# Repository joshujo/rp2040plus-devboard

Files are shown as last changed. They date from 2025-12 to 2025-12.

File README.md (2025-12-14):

# RP2040+ Devboard

This is a devboard that is designed to have a basic sensor, OLED screen, buttons and LEDs pre-embedded onto the board. The idea of this design was to have some basic hardware already available on the develepment board itself so an external bread board and some additional components with a kit and such is not needed to use it. Additionally, it can be used as a simple console or just a temperature monitor if desired. The board is designed to be extended with an additional 17 GPIO pins exposed to the user for prototyping. 

## Features

- 17 GPIO pins exposed
- HDC1080 accurate temperature + humidity sensor
- Buzzer
- OLED screen
- USB-C connector for power + data
- An additional power only USB-C connector designed to have an external battery plugged in
- 10 NeoPixel LEDs
- Programmable matrix buttons
- Up to 900mA +3V3
- Up to 3A VBUS
- 13 programmable buttons
- Designed to be used as is, no external bread board or components needed
- Moderate form factor of 100x40mm
- RP2040 comes with another I<sup>2</sup>C bus for more external components

# Datasheet

## Base
HDC1080 Addr: 1000000\
OLED Addr: 0111100 or 0111101\
Buzzer: GPIO24\
LED: GPIO25\
Neopixels: GPIO14

## Keypad
Shift: GPIO13\
ROW0: GPIO15\
ROW1: GPIO16\
ROW2: GPIO17\
ROW3: GPIO18\
COL0: GPIO19\
COL1: GPIO20\
COL2: GPIO21

## I<sud>2</sud>C
SDA: GPIO22\
SCL: GPIO23

# Schematic


# PCB


RP2040 Devboard

# BOM

| Item | Description | Quantity(For 5 units at minimum order amount) | Unit Price | Total Price | URL | Running Total |
| --- | --- | --- | --- | --- | --- | --- |
| CL05A105KP5NNNC | 10V 1uF X5R ±10% 0402 Ceramic Capacitors RoHS | 100 | 0.0017 | $0.17 | [https://www.lcsc.com/product-detail/C14445.html](https://www.lcsc.com/product-detail/C14445.html) | $0.17 |
| CL05B104KO5NNNC | 16V 100nF X7R ±10% 0402 Ceramic Capacitors RoHS | 100 | 0.0012 | $0.12 | [https://www.lcsc.com/product-detail/C1525.html](https://www.lcsc.com/product-detail/C1525.html) | $0.29 |
| CC0603JRNPO9BN330 | 50V 33pF NP0 ±5% 0603 Ceramic Capacitors RoHS | 100 | 0.0024 | $0.24 | [https://www.lcsc.com/product-detail/C107047.html](https://www.lcsc.com/product-detail/C107047.html) | $0.53 |
| CL10B104KB8NNNC | 50V 100nF X7R ±10% 0603 Ceramic Capacitors RoHS | 100 | 0.0026 | $0.26 | [https://www.lcsc.com/product-detail/C1591.html](https://www.lcsc.com/product-detail/C1591.html) | $0.79 |
| CL10A106KP8NNNC | 10V 10uF X5R ±10% 0603 Ceramic Capacitors RoHS | 50 | 0.0058 | $0.29 | [https://www.lcsc.com/product-detail/C19702.html](https://www.lcsc.com/product-detail/C19702.html) | $1.08 |
| CL10A105KB8NNNC | 50V 1uF X5R ±10% 0603 Ceramic Capacitors RoHS | 50 | 0.0049 | $0.25 | [https://www.lcsc.com/product-detail/C15849.html](https://www.lcsc.com/product-detail/C15849.html) | $1.33 |
| CL31A107MQHNNNE | 6.3V 100uF X5R ±20% 1206 Ceramic Capacitors RoHS | 20 | 0.0552 | $1.10 | [https://www.lcsc.com/product-detail/C15008.html](https://www.lcsc.com/product-detail/C15008.html) | $2.43 |
| KT-0805B | 5mA 100mcd 460nm~475nm Blue 100mW 3.1V 0805 LED Indication - Discrete RoHS | 50 | 0.0117 | $0.59 | [https://www.lcsc.com/product-detail/C2293.html](https://www.lcsc.com/product-detail/C2293.html) | $3.02 |
| CD4148WSP | 1A 4ns Independent 75V 1.25V@100mA 150mA 0805 Single Diodes RoHS | 100 | 0.0118 | $1.18 | [https://www.lcsc.com/product-detail/C30584799.html](https://www.lcsc.com/product-detail/C30584799.html) | $4.20 |
| WS2812B-2020 | SMD,2.2x2mm LED Addressable, Specialty RoHS | 60 | 0.0658 | $3.95 | [https://www.lcsc.com/product-detail/C965555.html](https://www.lcsc.com/product-detail/C965555.html) | $8.15 |
| TYPE-C-31-M-12 | 1 16P Type-C SMD USB, DVI, HDMI Connector Assemblies RoHS | 5 | 0.1762 | $0.88 | [https://www.lcsc.com/product-detail/C165948.html](https://www.lcsc.com/product-detail/C165948.html) | $9.03 |
| SKTDLHE010 | Without Bracket Rectangular Button No 3.9mm SPST SMD Tactile Switches RoHS | 10 | 0.1646 | $1.65 | [https://www.lcsc.com/product-detail/C380198.html](https://www.lcsc.com/product-detail/C380198.html) | $10.68 |
| SKSLLBE010 | 12V 2.2mm Round Button No 4.5mm SPST 50mA SMD,4.5x2.2mm Tactile Switches RoHS | 65 | 0.159 | $10.34 | [https://www.lcsc.com/product-detail/C358617.html](https://www.lcsc.com/product-detail/C358617.html) | $21.02 |
| RP2040 | 133MHz 30 LQFN-56(7x7) Microcontrollers RoHS | 3 | 0.9482 | $2.84 | [https://www.lcsc.com/product-detail/C2040.html](https://www.lcsc.com/product-detail/C2040.html) | $23.86 |
| HDC1080DMBR | ±2%RH -40℃~+125℃ 0%RH~100%RH I2C WSON-6(3x3) Humidity, Moisture Sensors RoHS | 5 | 0.9001 | $4.50 | [https://www.lcsc.com/product-detail/C82227.html](https://www.lcsc.com/product-detail/C82227.html) | $28.36 |
| NX3225GA-12MHZ-STD-CRG-2 | 8pF SMD3225-4P Crystals RoHS | 5 | 0.257 | $1.29 | [https://www.lcsc.com/product-detail/C481407.html](https://www.lcsc.com/product-detail/C481407.html) | $29.65 |
| MLT-8530 | 80dB Passive (Externally Driven) 2.7kHz 3.6V Electromagnetic SMD,8.5x8.5mm Alarms, Buzzers, and Sirens RoHS | 5 | 0.1941 | $0.97 | [https://www.lcsc.com/product-detail/C94599.html](https://www.lcsc.com/product-detail/C94599.html) | $30.62 |
| TPS2116DRLR | 2 Active High 2.5A SOT-583 Power Distribution Switches, Load Drivers RoHS | 5 | 0.3756 | $1.88 | [https://www.lcsc.com/product-detail/C3235557.html](https://www.lcsc.com/product-detail/C3235557.html) | $32.50 |
| HS96L03W2C03 | 0.96 128x64 SSD1315 I2C LCD, OLED, Graphic RoHS | 5 | 2.0084 | $10.04 | [https://www.lcsc.com/product-detail/C5248080.html](https://www.lcsc.com/product-detail/C5248080.html) | $42.54 |
| W25Q128JVSIQ | 128Mbit 2.7V~3.6V 133MHz SPI SOIC-8-208mil Memory (ICs) RoHS | 5 | 1.5657 | $7.83 | [https://www.lcsc.com/product-detail/C97521.html](https://www.lcsc.com/product-detail/C97521.html) | $50.37 |
| NCP1117ST33T3G | 62dB@(120Hz) Positive Fixed 3.3V SOT-223 Voltage Regulators - Linear, Low Drop Out (LDO) Regulators RoHS | 5 | 0.2315 | $1.16 | [https://www.lcsc.com/product-detail/C26537.html](https://www.lcsc.com/product-detail/C26537.html) | $51.53 |
| BSS138LT1G | 50V 200mA 225mW 5.6Ω@2.75V One N-channel SOT-23 Single FETs, MOSFETs RoHS | 20 | 0.0342 | $0.68 | [https://www.lcsc.com/product-detail/C82045.html](https://www.lcsc.com/product-detail/C82045.html) | $52.21 |
| FRC0603F27R4TS | 100mW 27.4Ω 75V ±100ppm/℃ Thick Film Resistor ±1% 0603 Chip Resistor - Surface Mount RoHS | 100 | 0.0009 | $0.09 | [https://www.lcsc.com/product-detail/C5126244.html](https://www.lcsc.com/product-detail/C5126244.html) | $52.30 |
| 0603WAF4700T5E | 100mW 470Ω 75V ±100ppm/℃ Thick Film Resistor ±1% 0603 Chip Resistor - Surface Mount RoHS | 100 | 0.0012 | $0.12 | [https://www.lcsc.com/product-detail/C23179.html](https://www.lcsc.com/product-detail/C23179.html) | $52.42 |
| AR03BTCX5001 | 100mW 5kΩ 75V ±25ppm/℃ Thin Film Resistor ±0.1% 0603 Chip Resistor - Surface Mount RoHS | 20 | 0.0302 | $0.60 | [https://www.lcsc.com/product-detail/C2828621.html](https://www.lcsc.com/product-detail/C2828621.html) | $53.02 |
| RC0603FR-07100RL | 100mW 100Ω 75V ±100ppm/℃ Thick Film Resistor ±1% 0603 Chip Resistor - Surface Mount RoHS | 100 | 0.0011 | $0.11 | [https://www.lcsc.com/product-detail/C105588.html](https://www.lcsc.com/product-detail/C105588.html) | $53.13 |
| FRC0603F5101TS | 100mW 5.1kΩ 75V ±100ppm/℃ Thick Film Resistor ±1% 0603 Chip Resistor - Surface Mount RoHS | 100 | 0.0009 | $0.09 | [https://www.lcsc.com/product-detail/C2907044.html](https://www.lcsc.com/product-detail/C2907044.html) | $53.22 |
| RC0603FR-0710KL | 100mW 10kΩ 75V ±100ppm/℃ Thick Film Resistor ±1% 0603 Chip Resistor - Surface Mount RoHS | 100 | 0.0011 | $0.11 | [https://www.lcsc.com/product-detail/C98220.html](https://www.lcsc.com/product-detail/C98220.html) | $53.33 |
| FRC0603F3302TS | 33kΩ 100mW 75V ±100ppm/℃ Thick Film Resistor ±1% 0603 Chip Resistor - Surface Mount RoHS | 100 | 0.0009 | $0.09 | [https://www.lcsc.com/product-detail/C2907028.html](https://www.lcsc.com/product-detail/C2907028.html) | $53.42 |
| PZ254V-11-03P | 3P 1x3P -40℃~+105℃ Pin Header Black 2.54mm 2.5mm 6mm 250V 3mm 1 3A Through Hole Through Hole,P=2.54mm Headers, Male Pins RoHS | 50 | 0.0162 | $0.81 | [https://www.lcsc.com/product-detail/C2937625.html](https://www.lcsc.com/product-detail/C2937625.html) | $54.23 |
| PZ254V-11-04P | 4P 1x4P -40℃~+105℃ Black Pin Header 2.54mm 2.5mm 6mm 250V 3mm 1 3A Through Hole Through Hole,P=2.54mm Headers, Male Pins RoHS | 20 | 0.0217 | $0.43 | [https://www.lcsc.com/product-detail/C2691448.html](https://www.lcsc.com/product-detail/C2691448.html) | $54.66 |
| 0402WGF1001TCE | 1kΩ 62.5mW 50V ±100ppm/℃ Thick Film Resistor ±1% 0402 Chip Resistor - Surface Mount RoHS | 100 | 0.0006 | $0.06 | [https://www.lcsc.com/product-detail/C11702.html](https://www.lcsc.com/product-detail/C11702.html) | $54.72 |
| KT-0805G | 5mA 430mcd 513nm\~528nm Emerald Green 100mW 2.6V\~3.1V 0805 LED Indication - Discrete RoHS | 50 | 0.0112 | $0.56 | [https://www.lcsc.com/product-detail/C2297.html](https://www.lcsc.com/product-detail/C2297.html) | $55.28 |
| TYPE-C 6P(073) | 1 6P -25℃~+85℃ Type-C SMD USB, DVI, HDMI Connector Assemblies RoHS | 10 | 0.0357 | $0.36 | [https://www.lcsc.com/product-detail/C668623.html](https://www.lcsc.com/product-detail/C668623.html) | $55.64 |

Plus $31.36 for the PCBs

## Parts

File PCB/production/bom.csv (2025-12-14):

Designator | Footprint | Quantity | Value | LCSC Part #
C1, C10 | 0402 | 2 | 1u
C11, C12, C2, C3, C4, C5, C6, C7, C8, C9 | 0402 | 10 | 100n
C13, C14 | 0603 | 2 | 10u
C15, C18, C19 | 0603 | 3 | 100n
C16, C17 | 0603 | 2 | 33p
C20 | 0603 | 1 | 1u
C21, C22, C23, C24, C25 | 1206 | 5 | 100u
D1, D2 | 0805 | 2 | KT-0805G
D10, D11, D12, D13, D14, D15, D3, D4, D5, D6, D7, D8, D9 | 0805 | 13 | CD4148W
D16, D17, D18, D19, D20, D21, D22, D23, D24, D25 | LED_WS2812B-2020_PLCC4_2.0x2.0mm | 10 | WS2812B-2020
J1 | USB_C_Receptacle_G-Switch_GT-USB-7010ASV | 1 | USB_C_Receptacle_USB2.0_14P
J2 | USB_C_Receptacle_GCT_USB4125-xx-x_6P_TopMnt_Horizontal | 1 | USB_C_Receptacle_PowerOnly_6P
J3, J4 | PinHeader_1x10_P2.54mm_Vertical | 2 | Conn_01x10_Pin
J5 | PinHeader_1x03_P2.54mm_Vertical | 1 | Conn_01x03_Pin
Q1 | SOT-23 | 1 | BSS138
R1, R2 | 0603 | 2 | 27.4
R10 | 0603 | 1 | 1k
R11 | 0402 | 1 | 1k
R12, R18, R19 | 0603 | 3 | 470
R13, R14, R15, R16 | 0603 | 4 | 5k
R17 | 0603 | 1 | 100
R3, R4, R5, R6 | 0603 | 4 | 5.1K
R7, R9 | 0603 | 2 | 10k
R8 | 0603 | 1 | 33k
SW1, SW10, SW11, SW12, SW13, SW14, SW15, SW2, SW3, SW4, SW5, SW6, SW7, SW8, SW9 | SW_Push_SPST_NO_Alps_SKRK | 15 | SW_Push
U1 | QFN-56-1EP_7x7mm_P0.4mm_EP3.2x3.2mm | 1 | RP2040
U2 | SOT-223-3_TabPin2 | 1 | NCP1117-3.3_SOT223
U3 | SOIC-8_5.3x5.3mm_P1.27mm | 1 | W25Q128JVS
U4 | HS96L03W2C03 | 1 | HS96L03W2C03
U5 | SOT-583-8 | 1 | TPS2116DRL
U7 | MLT-8530 | 1 | MLT-8530
U8 | Texas_S-PWSON-N6-HDC2080 | 1 | HDC1080
Y1 | Crystal_SMD_3225-4Pin_3.2x2.5mm_HandSoldering | 1 | NDK NX3225GA-12MHZ-STD-CRG-2

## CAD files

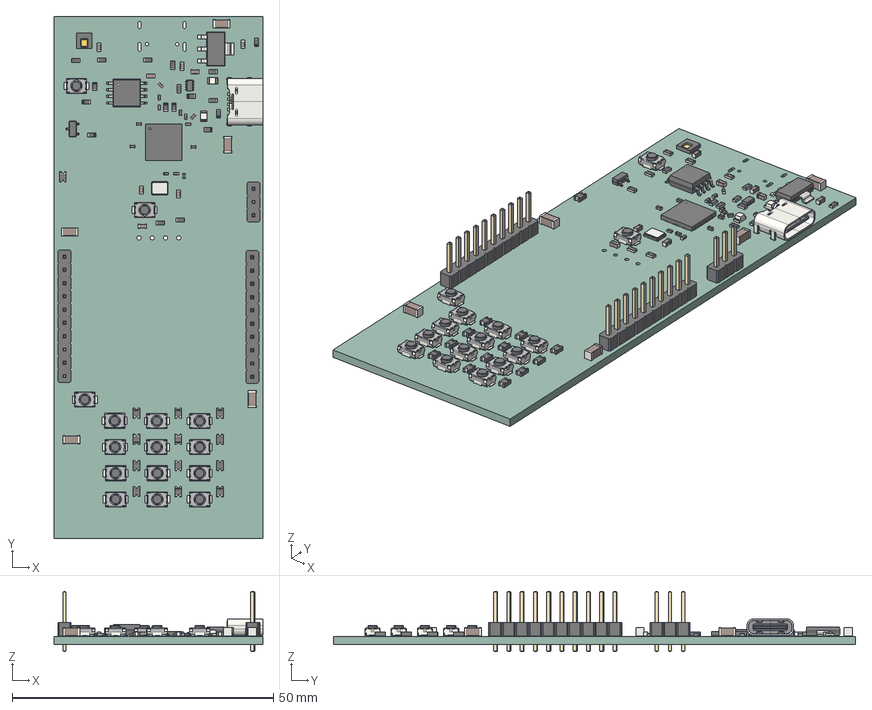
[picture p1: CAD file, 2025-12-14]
PCB/RP2040 Devboard.step
40.0 x 100.0 x 11.5 mm
D_0805_2012Metric x 13
R_0402_1005Metric
R_0603_1608Metric x 18
SW_Push_SPST_NO_Alps_SKRK x 15
C_1206_3216Metric x 5
Crystal_SMD_3225-4Pin_3.2x2.5mm
C_0402_1005Metric x 12
SOT-583-8
C_0603_1608Metric x 8
PinHeader_1x10_P2.54mm_Vertical x 2
PinHeader_1x03_P2.54mm_Vertical
LED_0805_2012Metric x 2
SOT-23
SOIC-8_5.3x5.3mm_P1.27mm
QFN-56-1EP_7x7mm_P0.4mm_EP3.2x3.2mm
SOT-223
USB_C_Receptacle_GCT_USB4125-xx-x_6P_TopMnt_Horizontal
Texas_S-PWSON-N6-HDC2080
RP2040 Devboard_PCB

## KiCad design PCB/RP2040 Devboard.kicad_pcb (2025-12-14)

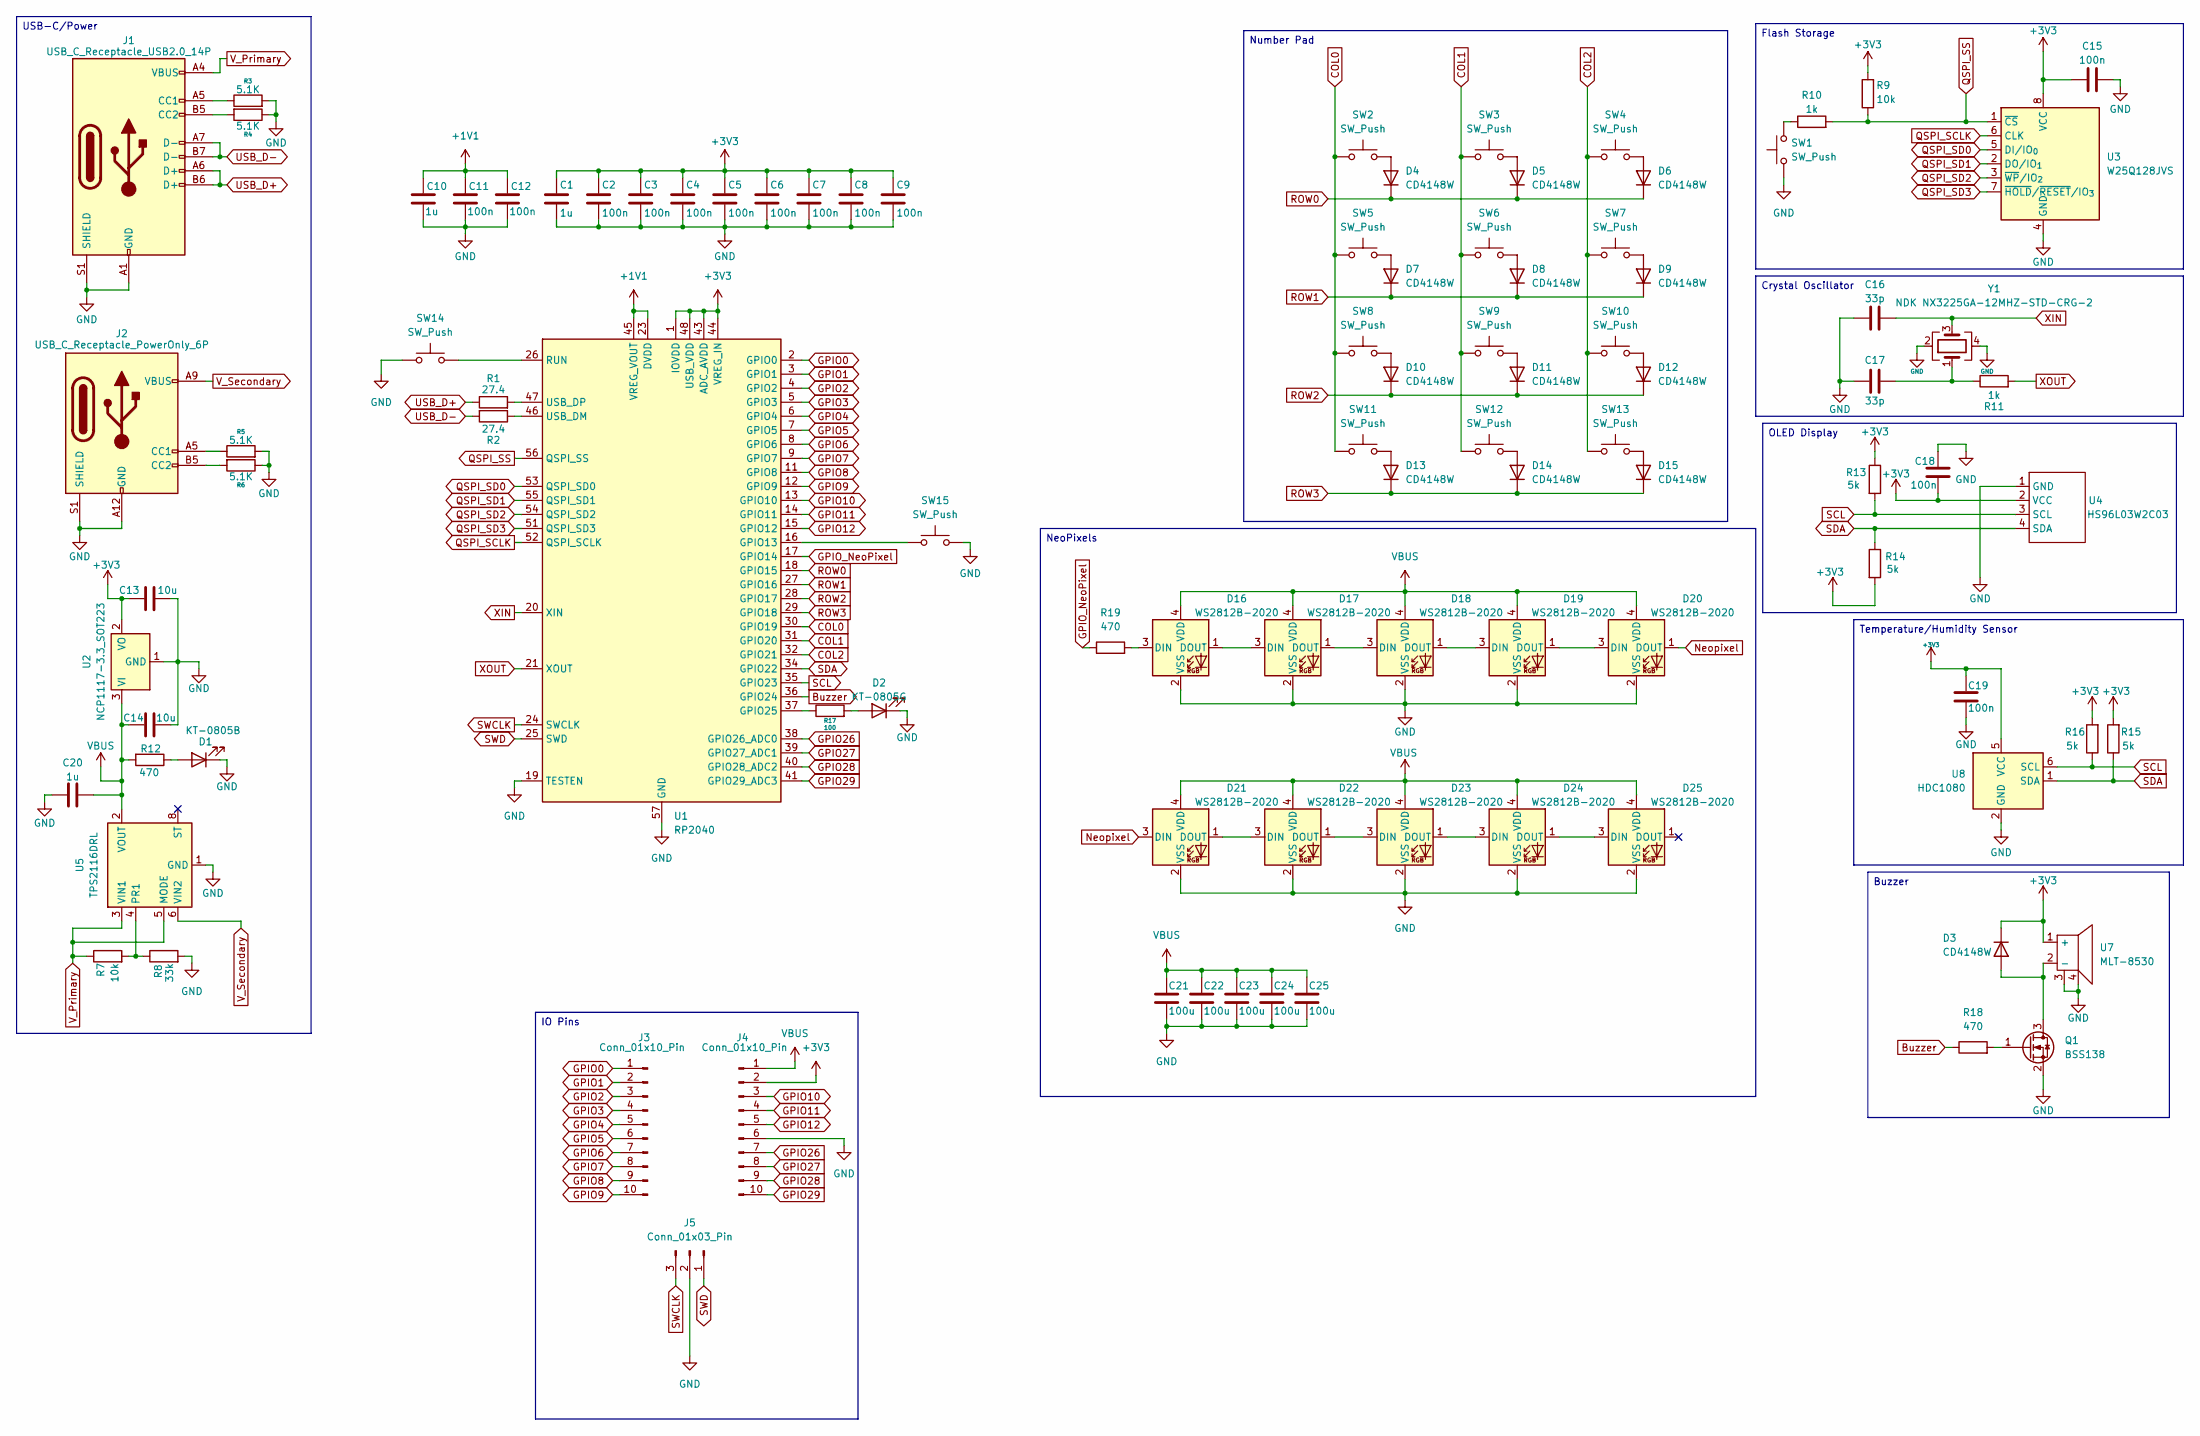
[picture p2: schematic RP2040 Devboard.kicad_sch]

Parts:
C1, C10: 1u; C_0402_1005Metric
C2, C3, C4, C5, C6, C7, C8, C9, C11, C12: 100n; C_0402_1005Metric
C13, C14: 10u; C_0603_1608Metric_Pad1.08x0.95mm_HandSolder
C15, C18, C19: 100n; C_0603_1608Metric_Pad1.08x0.95mm_HandSolder
C16, C17: 33p; C_0603_1608Metric_Pad1.08x0.95mm_HandSolder
C20: 1u; C_0603_1608Metric_Pad1.08x0.95mm_HandSolder
C21, C22, C23, C24, C25: 100u; C_1206_3216Metric_Pad1.33x1.80mm_HandSolder
D1: KT-0805B; LED_0805_2012Metric_Pad1.15x1.40mm_HandSolder
D2: KT-0805G; LED_0805_2012Metric_Pad1.15x1.40mm_HandSolder
D3, D4, D5, D6, D7, D8, D9, D10, D11, D12, D13, D14, D15: CD4148W; D_0805_2012Metric_Pad1.15x1.40mm_HandSolder
D16, D17, D18, D19, D20, D21, D22, D23, D24, D25: WS2812B-2020; LED_WS2812B-2020_PLCC4_2.0x2.0mm
J1: USB_C_Receptacle_USB2.0_14P; USB_C_Receptacle_G-Switch_GT-USB-7010ASV
J2: USB_C_Receptacle_PowerOnly_6P; USB_C_Receptacle_GCT_USB4125-xx-x_6P_TopMnt_Horizontal
J3, J4: Conn_01x10_Pin; PinHeader_1x10_P2.54mm_Vertical
J5: Conn_01x03_Pin; PinHeader_1x03_P2.54mm_Vertical
Q1: BSS138; SOT-23
R1, R2: 27.4; R_0603_1608Metric_Pad0.98x0.95mm_HandSolder
R3, R4, R5, R6: 5.1K; R_0603_1608Metric_Pad0.98x0.95mm_HandSolder
R7, R9: 10k; R_0603_1608Metric_Pad0.98x0.95mm_HandSolder
R8: 33k; R_0603_1608Metric_Pad0.98x0.95mm_HandSolder
R10: 1k; R_0603_1608Metric_Pad0.98x0.95mm_HandSolder
R11: 1k; R_0402_1005Metric
R12, R18, R19: 470; R_0603_1608Metric_Pad0.98x0.95mm_HandSolder
R13, R14, R15, R16: 5k; R_0603_1608Metric_Pad0.98x0.95mm_HandSolder
R17: 100; R_0603_1608Metric_Pad0.98x0.95mm_HandSolder
SW1, SW2, SW3, SW4, SW5, SW6, SW7, SW8, SW9, SW10, SW11, SW12, SW13, SW14, SW15: SW_Push; SW_Push_SPST_NO_Alps_SKRK
U1: RP2040; QFN-56-1EP_7x7mm_P0.4mm_EP3.2x3.2mm
U2: NCP1117-3.3_SOT223; SOT-223-3_TabPin2
U3: W25Q128JVS; SOIC-8_5.3x5.3mm_P1.27mm
U4: HS96L03W2C03
U5: TPS2116DRL; SOT-583-8
U7: MLT-8530
U8: HDC1080; Texas_S-PWSON-N6-HDC2080
Y1: NDK NX3225GA-12MHZ-STD-CRG-2; Crystal_SMD_3225-4Pin_3.2x2.5mm_HandSoldering

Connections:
+1V1: C10.1, C11.1, C12.1, U1.23 (DVDD), U1.45 (VREG_VOUT), U1.50 (DVDD)
+3V3: C1.1, C2.1, C3.1, C4.1, C5.1, C6.1, C7.1, C8.1, C9.1, C13.1, C15.1, C18.2, C19.1, D3.1 (K), J4.2, R9.2, R13.1, R14.2, R15.2, R16.2, U1.1 (IOVDD), U1.10 (IOVDD), U1.22 (IOVDD), U1.33 (IOVDD), U1.42 (IOVDD), U1.43 (ADC_AVDD), U1.44 (VREG_IN), U1.48 (USB_VDD), U1.49 (IOVDD), U2.2 (VO), U3.8 (VCC), U4.2 (VCC), U7.1 (+), U8.5 (VCC)
Buzzer: R18.1, U1.36 (GPIO24)
COL0: SW2.1, SW5.1, SW8.1, SW11.1, U1.30 (GPIO19)
COL1: SW3.1, SW6.1, SW9.1, SW12.1, U1.31 (GPIO20)
COL2: SW4.1, SW7.1, SW10.1, SW13.1, U1.32 (GPIO21)
GND: C1.2, C2.2, C3.2, C4.2, C5.2, C6.2, C7.2, C8.2, C9.2, C10.2, C11.2, C12.2, C13.2, C14.2, C15.2, C16.1, C17.2, C18.1, C19.2, C20.1, C21.2, C22.2, C23.2, C24.2, C25.2, D1.1 (K), D2.1 (K), D16.2 (VSS), D17.2 (VSS), D18.2 (VSS), D19.2 (VSS), D20.2 (VSS), D21.2 (VSS), D22.2 (VSS), D23.2 (VSS), D24.2 (VSS), D25.2 (VSS), J1.A1 (GND), J1.A12 (GND), J1.B1 (GND), J1.B12 (GND), J1.S1 (SHIELD), J2.A12 (GND), J2.B12 (GND), J2.S1 (SHIELD), J4.6, J5.2, Q1.2 (S), R3.2, R4.1, R5.2, R6.1, R8.2, SW1.1, SW14.1, SW15.2, U1.19 (TESTEN), U1.57 (GND), U2.1 (GND), U3.4 (GND), U4.1 (GND), U5.1 (GND), U7.3, U7.4, U8.2 (GND), Y1.2, Y1.4
GPIO0: J3.1, U1.2 (GPIO0)
GPIO1: J3.2, U1.3 (GPIO1)
GPIO2: J3.3, U1.4 (GPIO2)
GPIO3: J3.4, U1.5 (GPIO3)
GPIO4: J3.5, U1.6 (GPIO4)
GPIO5: J3.6, U1.7 (GPIO5)
GPIO6: J3.7, U1.8 (GPIO6)
GPIO7: J3.8, U1.9 (GPIO7)
GPIO8: J3.9, U1.11 (GPIO8)
GPIO9: J3.10, U1.12 (GPIO9)
GPIO10: J4.3, U1.13 (GPIO10)
GPIO11: J4.4, U1.14 (GPIO11)
GPIO12: J4.5, U1.15 (GPIO12)
GPIO26: J4.7, U1.38 (GPIO26_ADC0)
GPIO27: J4.8, U1.39 (GPIO27_ADC1)
GPIO28: J4.9, U1.40 (GPIO28_ADC2)
GPIO29: J4.10, U1.41 (GPIO29_ADC3)
GPIO_NeoPixel: R19.1, U1.17 (GPIO14)
Neopixel: D20.1 (DOUT), D21.3 (DIN)
unnamed: C17.1, R11.1, Y1.1
unnamed: D1.2 (A), R12.1
unnamed: D2.2 (A), R17.2
unnamed: D3.2 (A), Q1.3 (D), U7.2 (-)
unnamed: D4.2 (A), SW2.2
unnamed: D5.2 (A), SW3.2
unnamed: D6.2 (A), SW4.2
unnamed: D7.2 (A), SW5.2
unnamed: D8.2 (A), SW6.2
unnamed: D9.2 (A), SW7.2
unnamed: D10.2 (A), SW8.2
unnamed: D11.2 (A), SW9.2
unnamed: D12.2 (A), SW10.2
unnamed: D13.2 (A), SW11.2
unnamed: D14.2 (A), SW12.2
unnamed: D15.2 (A), SW13.2
unnamed: D16.3 (DIN), R19.2
unnamed: D16.1 (DOUT), D17.3 (DIN)
unnamed: D17.1 (DOUT), D18.3 (DIN)
unnamed: D18.1 (DOUT), D19.3 (DIN)
unnamed: D19.1 (DOUT), D20.3 (DIN)
unnamed: D21.1 (DOUT), D22.3 (DIN)
unnamed: D22.1 (DOUT), D23.3 (DIN)
unnamed: D23.1 (DOUT), D24.3 (DIN)
unnamed: D24.1 (DOUT), D25.3 (DIN)
unnamed: J1.A5 (CC1), R3.1
unnamed: J1.B5 (CC2), R4.2
unnamed: J2.A5 (CC1), R5.1
unnamed: J2.B5 (CC2), R6.2
unnamed: Q1.1 (G), R18.2
unnamed: R10.1, SW1.2
unnamed: SW15.1, U1.16 (GPIO13)
unnamed: R17.1, U1.37 (GPIO25)
unnamed: SW14.2, U1.26 (RUN)
unnamed: R2.1, U1.46 (USB_DM)
unnamed: R1.2, U1.47 (USB_DP)
unnamed: R7.2, R8.1, U5.4 (PR1)
QSPI_SCLK: U1.52 (QSPI_SCLK), U3.6 (CLK)
QSPI_SD0: U1.53 (QSPI_SD0), U3.5 (DI/IO_{0})
QSPI_SD1: U1.55 (QSPI_SD1), U3.2 (DO/IO_{1})
QSPI_SD2: U1.54 (QSPI_SD2), U3.3 (~WP/IO_{2})
QSPI_SD3: U1.51 (QSPI_SD3), U3.7 (~HOLD/~RESET/IO_{3})
QSPI_SS: R9.1, R10.2, U1.56 (QSPI_SS), U3.1 (~CS)
ROW0: D4.1 (K), D5.1 (K), D6.1 (K), U1.18 (GPIO15)
ROW1: D7.1 (K), D8.1 (K), D9.1 (K), U1.27 (GPIO16)
ROW2: D10.1 (K), D11.1 (K), D12.1 (K), U1.28 (GPIO17)
ROW3: D13.1 (K), D14.1 (K), D15.1 (K), U1.29 (GPIO18)
SCL: R13.2, R16.1, U1.35 (GPIO23), U4.3 (SCL), U8.6 (SCL)
SDA: R14.1, R15.1, U1.34 (GPIO22), U4.4 (SDA), U8.1 (SDA)
SWCLK: J5.3, U1.24 (SWCLK)
SWD: J5.1, U1.25 (SWD)
USB_D+: J1.A6 (D+), J1.B6 (D+), R1.1
USB_D-: J1.A7 (D-), J1.B7 (D-), R2.2
VBUS: C14.1, C20.2, C21.1, C22.1, C23.1, C24.1, C25.1, D16.4 (VDD), D17.4 (VDD), D18.4 (VDD), D19.4 (VDD), D20.4 (VDD), D21.4 (VDD), D22.4 (VDD), D23.4 (VDD), D24.4 (VDD), D25.4 (VDD), J4.1, R12.2, U2.3 (VI), U5.2 (VOUT), U5.7 (VOUT)
V_Primary: J1.A4 (VBUS), J1.A9 (VBUS), J1.B4 (VBUS), J1.B9 (VBUS), R7.1, U5.3 (VIN1), U5.5 (MODE)
V_Secondary: J2.A9 (VBUS), J2.B9 (VBUS), U5.6 (VIN2)
XIN: C16.2, U1.20 (XIN), Y1.3
XOUT: R11.2, U1.21 (XOUT)

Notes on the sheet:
NeoPixels
IO Pins
OLED Display
Number Pad
Crystal Oscillator
Buzzer
USB-C/Power
Temperature/Humidity Sensor
Flash Storage

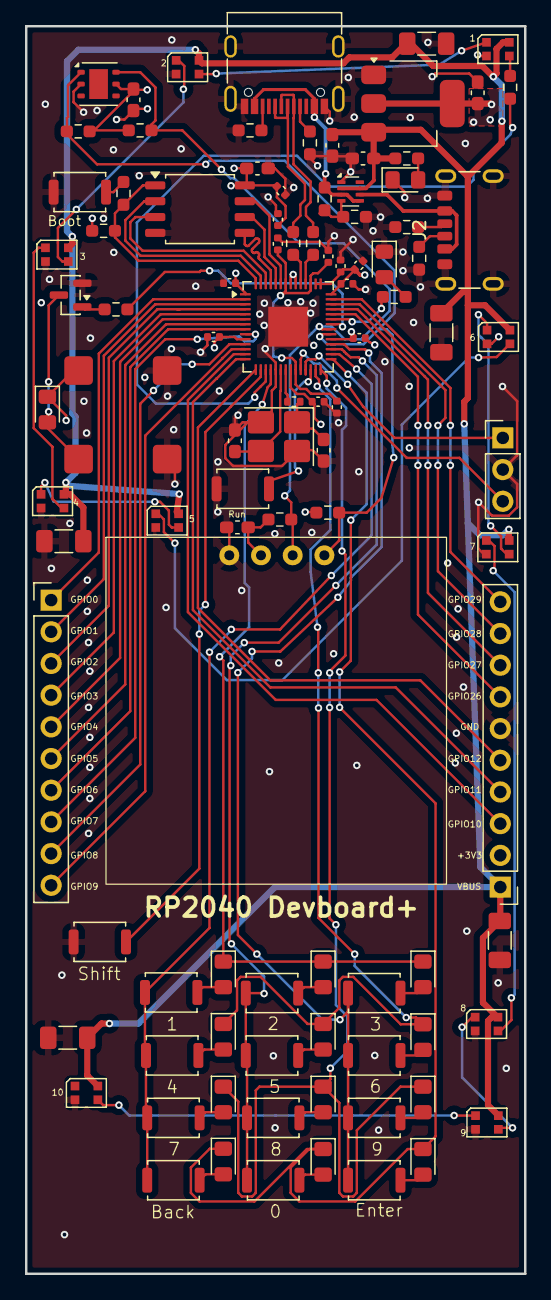
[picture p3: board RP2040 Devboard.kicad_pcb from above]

Board: 4 copper layers, 40.0 x 100.0 mm, 98 parts (0 on the bottom side), 84 nets.

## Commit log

2025-12-14 Added the necessary production files
    [RP2040 BOM.csv, RP2040 Devboard.kicad_pcb, RP2040 Devboard.kicad_sch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]
2025-12-14 Updated all the files and fixed any caught mistakes
    [BOM.csv, RP2040 Devboard.kicad_pcb, RP2040 Devboard.step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]
2025-12-14 Fixed missing items in BOM
